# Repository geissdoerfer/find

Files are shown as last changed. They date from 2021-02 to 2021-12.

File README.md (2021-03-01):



# Efficient neighbor discovery and synchronization in battery-free wireless networks with FIND and FLYNC

This repository hosts the artifacts accompanying our NSDI 2021 paper, which introduces FIND and FLYNC.
FIND is the first neighbor discovery protocol for battery-free networks; it uses randomized waiting to minimize discovery latency in the face of intermittency.
FLYNC synchronizes indoor light harvesting devices to the powerline-induced brightness variations of state-of-the-art lamps; it further speeds up discovery when used in tandem with FIND.

In addition to the Python implementation of the analytical FIND model, we provide the hardware design of the prototype battery-free node and the source code of the firmware we used to evaluate FIND and FLYNC.

To get an overview, visit [our website](https://find.nes-lab.org).
For a detailed description and evaluation results, take a look at [our paper](https://nes-lab.org/pubs/2021-Geissdoerfer-Find.pdf).

## FIND Python Model

We provide a Python implementation of the analytical model of the FIND protocol, allowing to reproduce key results of our paper.
For a detailed description and examples, check out the [`/model`](./model/) directory.

## Hardware Design

We built a tiny, battery-free wireless node to evaluate FIND and FLYNC on real hardware.
The [`/hardware`](./hardware) directory contains the corresponding schematics and layout files.

## Firmware

The C code in the [`/firmware`](./firmware) directory implements the FIND protocol and the FLYNC synchronization mechanism on our prototype battery-free node.

## People

FIND and FLYNC are being developed at the Networked Embedded Systems Lab at TU Dresden.

The main contributors are:

 - [Kai Geissdoerfer](https://scholar.google.com/citations?user=k8YZfQEAAAAJ)
 - [Marco Zimmerling](https://wwwpub.zih.tu-dresden.de/~mzimmerl/)

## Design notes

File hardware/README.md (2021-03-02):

# FIND and FLYNC hardware

This directory contains the design files for a 29mm x 29mm battery-free wireless node.
The node is powered by three IXYS KXOB025-5X3F solar panels and buffers energy in a 47uF multi-layer ceramic capacitor.
It implements a circuit to extract a clock signal from variations of the solar panel current caused by powerline flicker of lamps.

Key specifications:
 - TI BQ25505 boost charger with maximum power point tracking
 - Nordic Semiconductor nRF52840 2.4GHz wireless MCU (BLE/802.15.4)
    - ARM Cortex-M4F 64MHz CPU with FPU
    - 1MB flash, 256kB S-RAM
 - 47uF capacitor in 0805 package

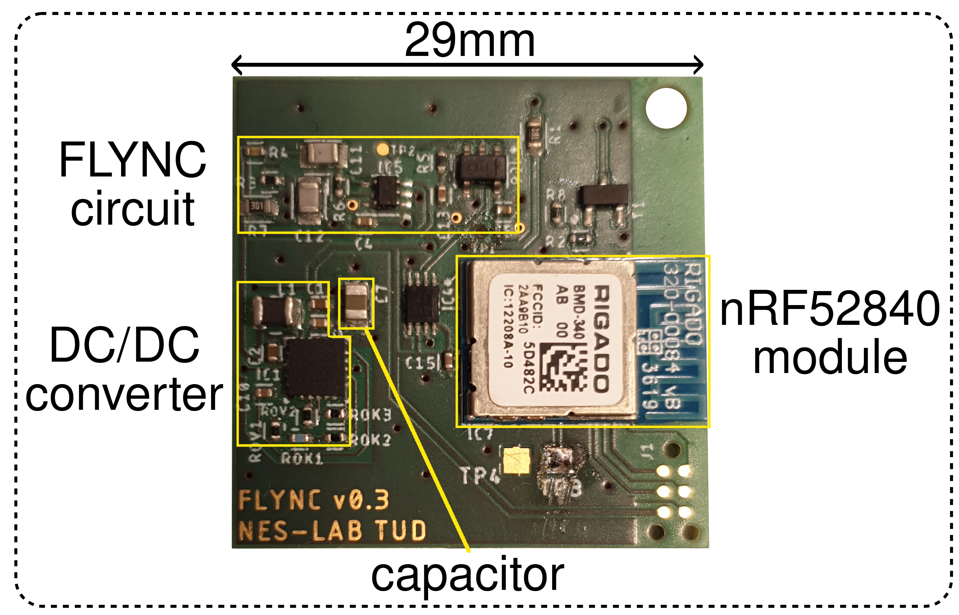
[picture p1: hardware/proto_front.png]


If you have questions or need help with manufacturing the hardware, get in touch with us!

## Pinout

We use a head-less 6-pin Tag-Connect header to break out 6 signals from the FLYNC node.

| Pin number | Signal | Description |
|---|---|---|
| 1 | SWDIO | ARM Serial Wire Debug I/O |
| 2 | SWDCLK | ARM Serial Wire Debug Clock |
| 3 | PIN_DBG1 | nRF52 GPIO for debugging via e.g. UART |
| 4 | PIN_DBG2 | nRF52 GPIO for debugging via e.g. UART |
| 5 | VCC | Output of BQ25504 and supply of nRF52  |
| 6 | GND | Ground |

Use a [Tag-Connect TC2030-IDC-NL cable](https://www.tag-connect.com/product/tc2030-idc-nl) cable to connect to this header:

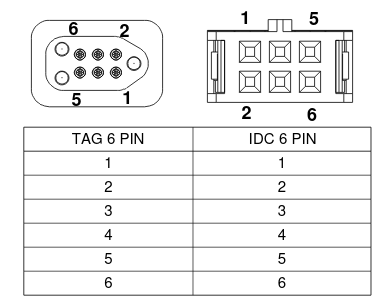
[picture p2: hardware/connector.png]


## Development setup

We found the following setup convenient:

 - Lab bench power supply with 3.3V output
 - Breadboard and some jumper cables
 - [J-Link Mini Edu](https://www.segger.com/products/debug-probes/j-link/models/j-link-edu-mini/)
 - SPST push button
 - [Tag-Connect TC2030-IDC-NL cable](https://www.tag-connect.com/product/tc2030-idc-nl)

Connect the power supply GND to the breadboard GND rail and the power supply 3.3V to the breadboard power rail.
Connect GND (pin 6) of the cable to the GND rail on the breadboard and VCC (pin 5) of the cable to any unused row of the breadboard.
Connect the push button between this rail (with node VCC) and the breadboard 3.3V rail.
Connect the Vref of the J-Link to the 3.3V rail of the breadboard and the GND of the J-Link to the GND rail of the breadboard.
Finally, connect the SWDIO and SWDCLK pins of the J-Link to pins 1 and 2 of the cable.

By pushing the button, you can temporarily power the node from the 3.3V power supply to flash new code.
After releasing the push button, the node will continue to run from harvested energy.

For debugging, you can attach a logic analyzer or scope to pins 3 and 4 of the cable and an analog channel to the node's voltage rail (pin 5).
Keep in mind that there may be significant current flowing into these inputs, interfering with the node's operation.

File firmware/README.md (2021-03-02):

# FIND and FLYNC firmware

The C code in this directory runs the FIND protocol together with the FLYNC synchronization mechanism on the battery-free node hardware provided in `../hardware`.

## Prerequisites

To get started, you need:

 - Two battery-free sensor nodes
 - A [Tag-Connect TC2030-IDC-NL cable](https://www.tag-connect.com/product/tc2030-idc-nl)
 - A programmer compatible with SWD and the nRF52. For example, the [J-Link Mini Edu](https://www.segger.com/products/debug-probes/j-link/models/j-link-edu-mini/), the [Black Magic Probe](https://github.com/blacksphere/blackmagic/wiki) or a [nRF52-DK](https://www.nordicsemi.com/Software-and-Tools/Development-Kits/nRF52-DK)
 - A 3.3V power supply
 - A reasonably bright lamp with sufficient powerline flicker. All incandescent and fluorescent lamps as well as most cheap LED lamps should work

## Getting started

### Building
 - Make sure you have the [GNU Arm Embedded Toolchain](https://developer.arm.com/tools-and-software/open-source-software/developer-tools/gnu-toolchain/gnu-rm/downloads) installed
 - If `arm-none-eabi-gcc` is not in your path, set the environment variable `GNU_INSTALL_ROOT` accordingly, e.g., `export GNU_INSTALL_ROOT=/opt/toolchain/` (note the trailing foreslash)
 - Download the nRF5 SDK from [here.](https://www.nordicsemi.com/Software-and-tools/Software/nRF5-SDK/Download "here") (you don't need a SoftDevice) and extract it
 - Set the environment variables `SDK_ROOT` to the corresponding absolute path, e.g., `export SDK_ROOT=/home/user/nRF5_SDK_17.0.2_d674dde/`
 - run `make`

### Flashing
 - Download and install the [nRF-Command-Line-Tools](https://www.nordicsemi.com/Software-and-tools/Development-Tools/nRF-Command-Line-Tools/Download) following the official instructions.
 - Connect your programmer to your PC
 - Connect your programmer to one of the FLYNC sensor nodes according to the corresponding [README](../hardware/README.md)
 - run `make flash`

### Testing

After flashing the two nodes, you can place them next to each other under the lamp.
You should see their LEDs flashing simultaneously every now and then, indicating a successful rendezvous.
Cover the solar panels with your hands to reset the nodes.
Because of the small energy storage, they lose track of time and state after a few seconds.
After removing your hands, you should soon see the nodes blinking simultaneously again, indicating another successful rendezvous.
Take one node to another lamp of the same type close by, i.e., within radio range.
You should still see each of the nodes blinking occasionally.

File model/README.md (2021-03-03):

# FIND model

This directory contains a Python implementation of the analytical FIND model presented in Section 2 of our NSDI 2021 paper.
As illustrated below, the model allows to compute the network discovery latency as a function of several key parameters (e.g., delay distribution, charging times of the nodes).
It is also possible to obtain more detailed insights by computing the probability for a node to become active in a slot and the probability for a link to be discovered in a slot.

## Installation

Install the python package together with the requirements for the examples using either

```
pip install neslab.find[examples]
```

or

```
pipenv install neslab.find[examples]
```

## Usage

Instantiate the model with a uniform distribution with scale parameter 10 and three nodes with charging times of 100, 125 and 200 slots that become active for the first time without an offset:

```python
import matplotlib.pyplot as plt
from neslab.find import Model

m = Model(10, "Uniform", [100, 125, 200], offset=0)
```

Compute for every node the probability of being active in a slot and plot the results:

```python
act = m.activity()
plt.plot(act[:2000])
plt.show()
```

Compute the cumulative distribution function (cdf) of the slot in which each of the three links between the three nodes is discovered and plot the results:

```python
cdfs = m.cdf()
plt.plot(cdfs)
plt.show()
```

Compute the fraction of discovered links and plot the result:

```python
dff = m.disco_frac()
plt.plot(dff)
plt.show()
```

Compute the discovery latency:

```python
lat = m.disco_latency()
print(f"Discovery latency: {lat} slots")
```

## Examples

We provide more involved example scripts in the [examples](./examples) directory:

To compare the probability of activity and the cdf of the corresponding discovery latency of two nodes with a charging time of 30 and 60 slots, using a uniform delay distribution, call

```
python examples/plot_example.py
```

To compare the discovery latency of two nodes when using different distributions across a range of their scale parameters, run

```
python examples/compare_dists.py
```

To plot the discovery latency of a clique of nodes over the node density, run

```
python examples/plot_density.py
```

To optimize the scale parameter of the geometric distribution to a range of charging times, run

```
python examples/optimize_scale.py
```

## Reproduce key results

We used the code provided in this directory to gain the insights presented in Section 2 of [our NSDI 2021 paper](https://nes-lab.org/pubs/2021-Geissdoerfer-Find.pdf).
We invite you to reproduce our results with the scripts provided in the [reproducibility](./reproducibility) directory.
Figures 3 and 4 can be reproduced with the script `examples/plot_example.py`.
The calculations for Figures 5 and 6, and for the lookup table for the online implementation take significant computing resources and require a high performance computing system with a large number of CPUs to complete in a reasonable amount of time.
We use [ray](https://ray.io/) to run the calculations on a distributed memory computing cluster.

### Setup your cluster

Install `ray` and `neslab.find` on all nodes in your cluster. The exact installation procedure depends on the specific cluster setup and your access rights. If in doubt, contact the cluster provider.

First, setup the `head` node responsible for managing the workload across the cluster by starting the head process with:

```
ray start --block --head --redis-password=yourpassword
```

Next, start a worker process on each other node in your cluster, providing the IP address of your head node as  `address`:

```
ray start --block --address=[IP of head node] --redis-password=yourpassword
```

### Comparing distributions

To reproduce the results shown in Figure 5 in our paper, you can compute the neighbor discovery performance of different distributions for a higher number of sampling points than with the example from `examples/compare_dists` according to the following instructions.

Login to any of the nodes in the cluster, clone the repository and run

```
python reproducibility/compute_dists.py -a [IP of head node] -p yourpassword -o results_dists.csv
```

Copy the `results_dists.csv` to your local machine and generate the plot with

```
python reproducibility/plot_dists.py -i results_dists.csv
```

### Fit the scale parameter for various scenarios

As a basis for reproducing the results shown in Figure 6 in our paper, and to generate the lookup table for the online implementation, first fit the scale parameter of the geometric distribution for different combinations of charging time and number of nodes with

```
python reproducibility/fit_scale.py -a [IP of head node] -p yourpassword -o results_scale.csv
```

This will store the results in a csv file under `results_scale.csv`.

### Discovery latency versus network density

To reproduce Figure 6 in our paper, use the results from the previous step to compute ND performance for different strategies and increasing network densities by running (on the cluster)

```
python reproducibility/compute_density.py -a [IP of head node] -p yourpassword -i results_scale.csv -o results_density.csv
```

Copy the `results_density.csv` to your local machine and generate the plot with

```
python reproducibility/plot_density.py -i results_density.csv
```

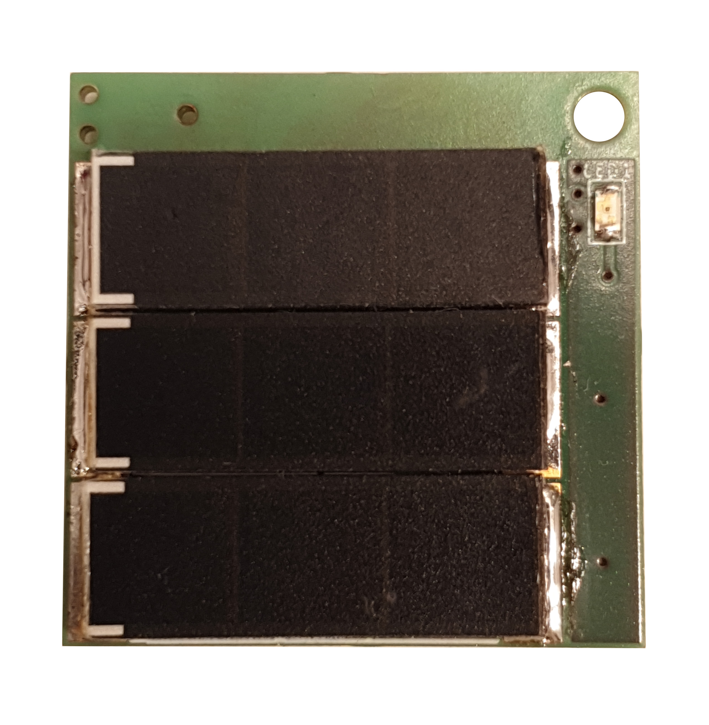
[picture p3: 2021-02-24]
hardware/proto_back.jpg

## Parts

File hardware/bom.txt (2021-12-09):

You find the BOM under https://octopart.com/bom-tool/tjKuMvbW

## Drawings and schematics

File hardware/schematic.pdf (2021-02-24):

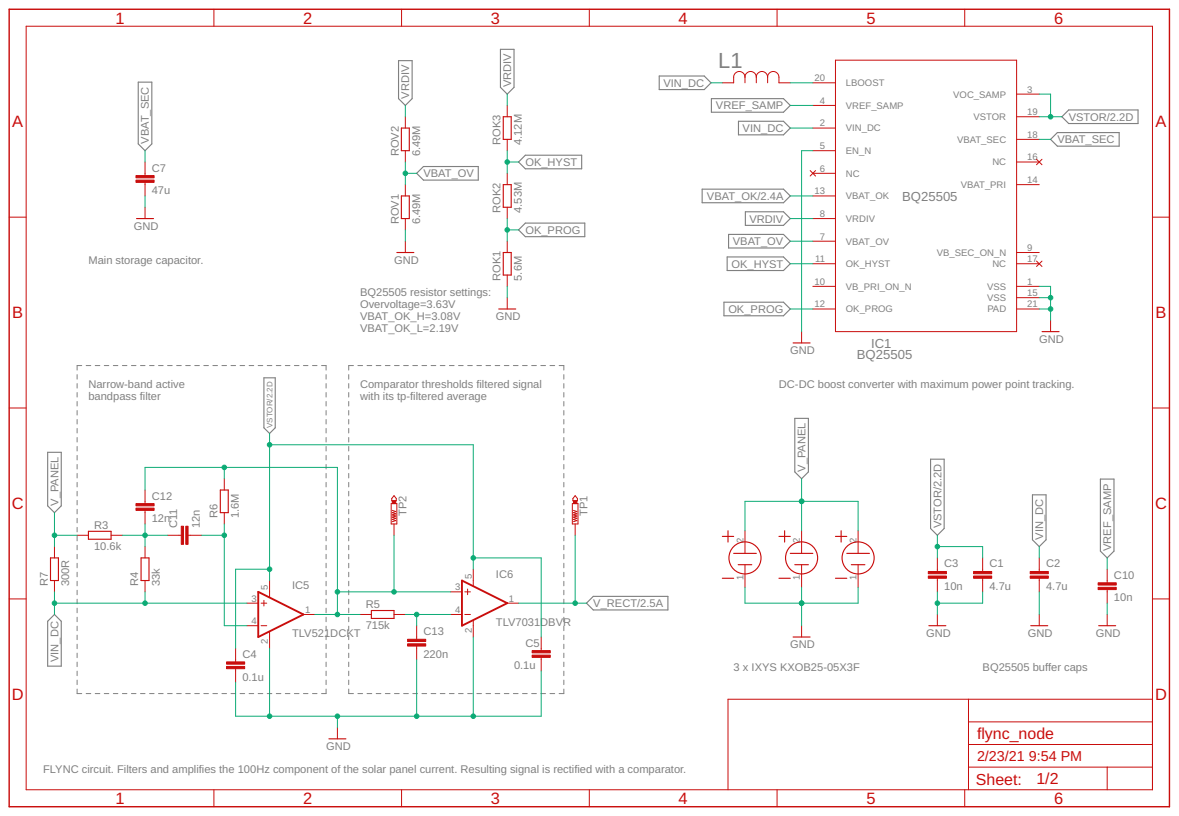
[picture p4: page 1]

FLYNC circuit. Filters and amplifies the 100Hz component of the solar panel current. Resulting signal is rectified with a comparator.

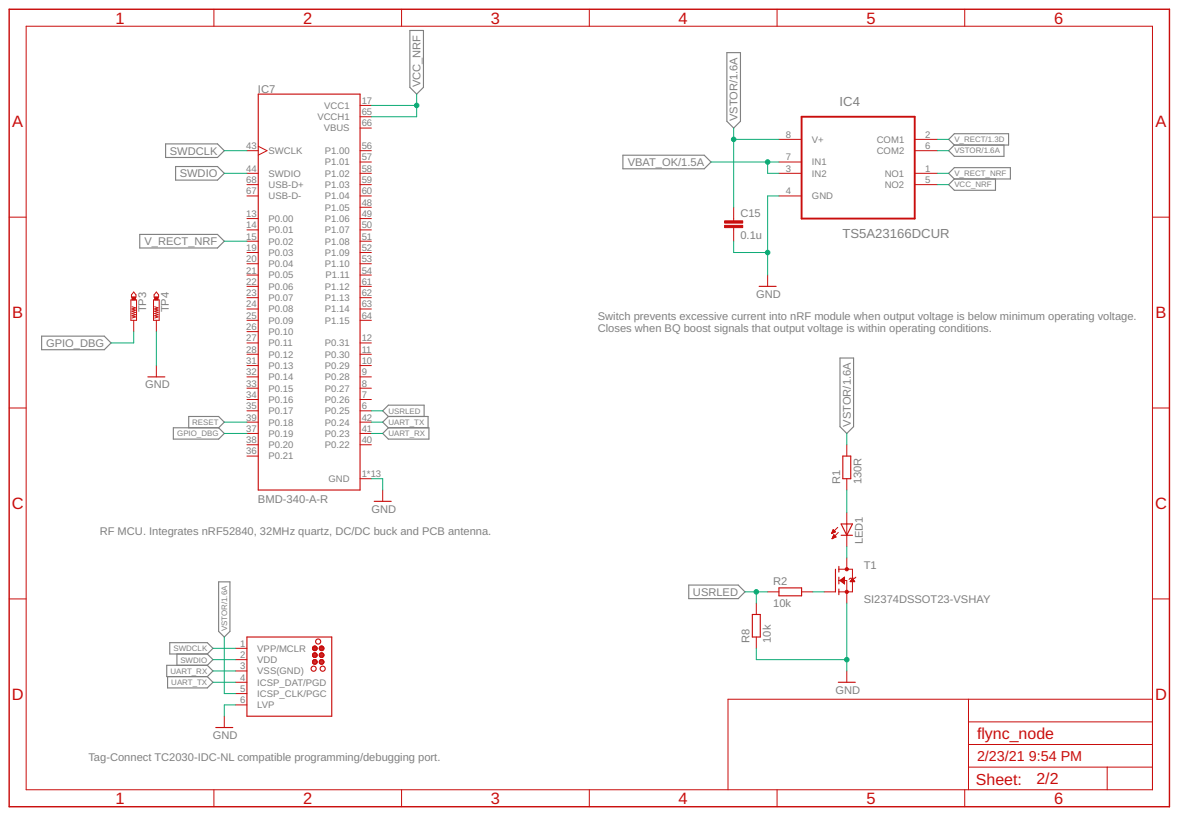
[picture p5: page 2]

Switch prevents excessive current into nRF module when output voltage is below minimum operating voltage. Closes when BQ boost signals that output voltage is within operating conditions.

RF MCU. Integrates nRF52840, 32MHz quartz, DC/DC buck and PCB antenna.

Tag-Connect TC2030-IDC-NL compatible programming/debugging port.

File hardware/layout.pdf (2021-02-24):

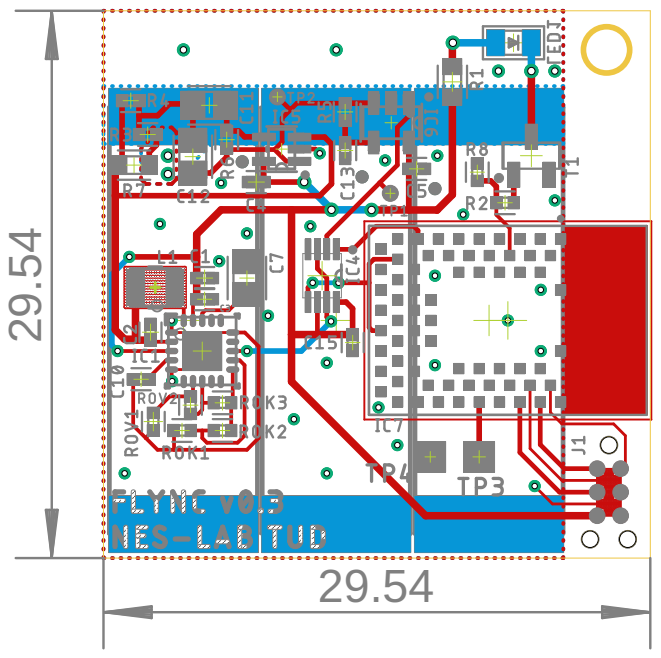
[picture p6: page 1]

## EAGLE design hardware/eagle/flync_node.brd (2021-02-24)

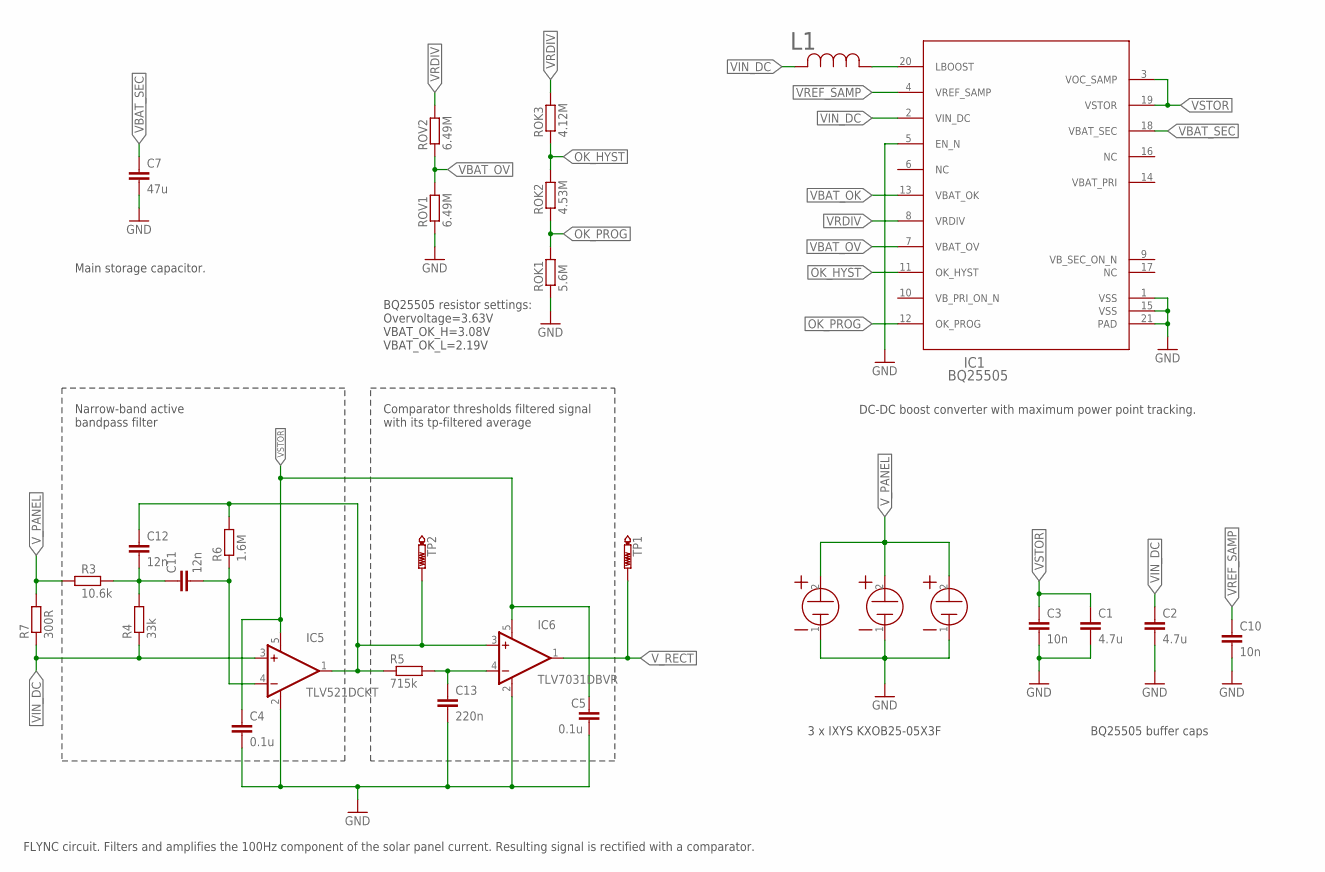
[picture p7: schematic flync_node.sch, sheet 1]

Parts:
C1, C2: 4.7u; CAPC1005X55
C3, C10: 10n; CAPC1005X55
C4, C5: 0.1u; CAPC1005X55
C7: 47u; CAPC2012X145
C11, C12: 12n; CAPC2012X145
C13: 220n; CAPC1005X55
H1, H2, H3: IXYSKXOB25-05X3F; IXYS23X8
IC1: BQ25505; RGR0020A
IC5: TLV521DCKT; DCK5
IC6: TLV7031DBVR; DBV5-L
L1: LBR2518T220KIND1007_47N_TAI-L; IND1007_47N_TAI-L
R3: 10.6k; RESC1005X40
R4: 33k; RESC1005X40
R5: 715k; RESC1005X40
R6: 1.6M; RESC1005X40
R7: 300R; RESC1608X55
ROK1: 5.6M; RESC1005X40
ROK2: 4.53M; RESC1005X40
ROK3: 4.12M; RESC1005X40
ROV1, ROV2: 6.49M; RESC1005X40
TP1, TP2: PTR1TP08R; TP08R

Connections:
GND: C1.2, C2.2, C3.2, C4.2, C5.2, C7.2, C10.2, C13.2, H1.1, H2.1, H3.1, IC1.1 (VSS), IC1.5 (EN_N), IC1.15 (VSS), IC1.21 (PAD), IC5.2 (V-), IC6.2 (V-), ROK1.1, ROV1.1; also elsewhere on the board
unnamed: IC1.20 (LBOOST), L1.1
unnamed: C11.1, C12.2, R3.2, R4.2
unnamed: C11.2, IC5.4 (-IN), R6.1
unnamed: C12.1, IC5.1 (OUT), IC6.3 (+IN), R5.1, R6.2, TP2.TP
unnamed: C13.1, IC6.4 (-IN), R5.2
OK_HYST: IC1.11 (OK_HYST), ROK2.2, ROK3.1
OK_PROG: IC1.12 (OK_PROG), ROK1.2, ROK2.1
VBAT_OK: IC1.13 (VBAT_OK); also elsewhere on the board
VBAT_OV: IC1.7 (VBAT_OV), ROV1.2, ROV2.1
VBAT_PRI: IC1.14 (VBAT_PRI)
VBAT_SEC: C7.1, IC1.18 (VBAT_SEC)
VB_SEC_ON_N: IC1.9 (VB_SEC_ON_N)
VIN_DC: C2.1, IC1.2 (VIN_DC), IC5.3 (+IN), L1.2, R4.1, R7.1
VRDIV: IC1.8 (VRDIV), ROK3.2, ROV2.2
VREF_SAMP: C10.1, IC1.4 (VREF_SAMP)
VSTOR: C1.1, C3.1, C4.1, C5.1, IC1.3 (VOC_SAMP), IC1.19 (VSTOR), IC5.5 (V+), IC6.5 (V+); also elsewhere on the board
V_PANEL: H1.2, H2.2, H3.2, R3.1, R7.2
V_RECT: IC6.1 (OUT), TP1.TP; also elsewhere on the board

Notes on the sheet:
FLYNC circuit. Filters and amplifies the 100Hz component of the solar panel current. Resulting signal is rectified with a comparator.
Narrow-band active bandpass filter
Comparator thresholds filtered signal with its tp-filtered average
DC-DC boost converter with maximum power point tracking.
BQ25505 resistor settings: Overvoltage=3.63V VBAT_OK_H=3.08V VBAT_OK_L=2.19V
Main storage capacitor.
BQ25505 buffer caps
3 x IXYS KXOB25-05X3F

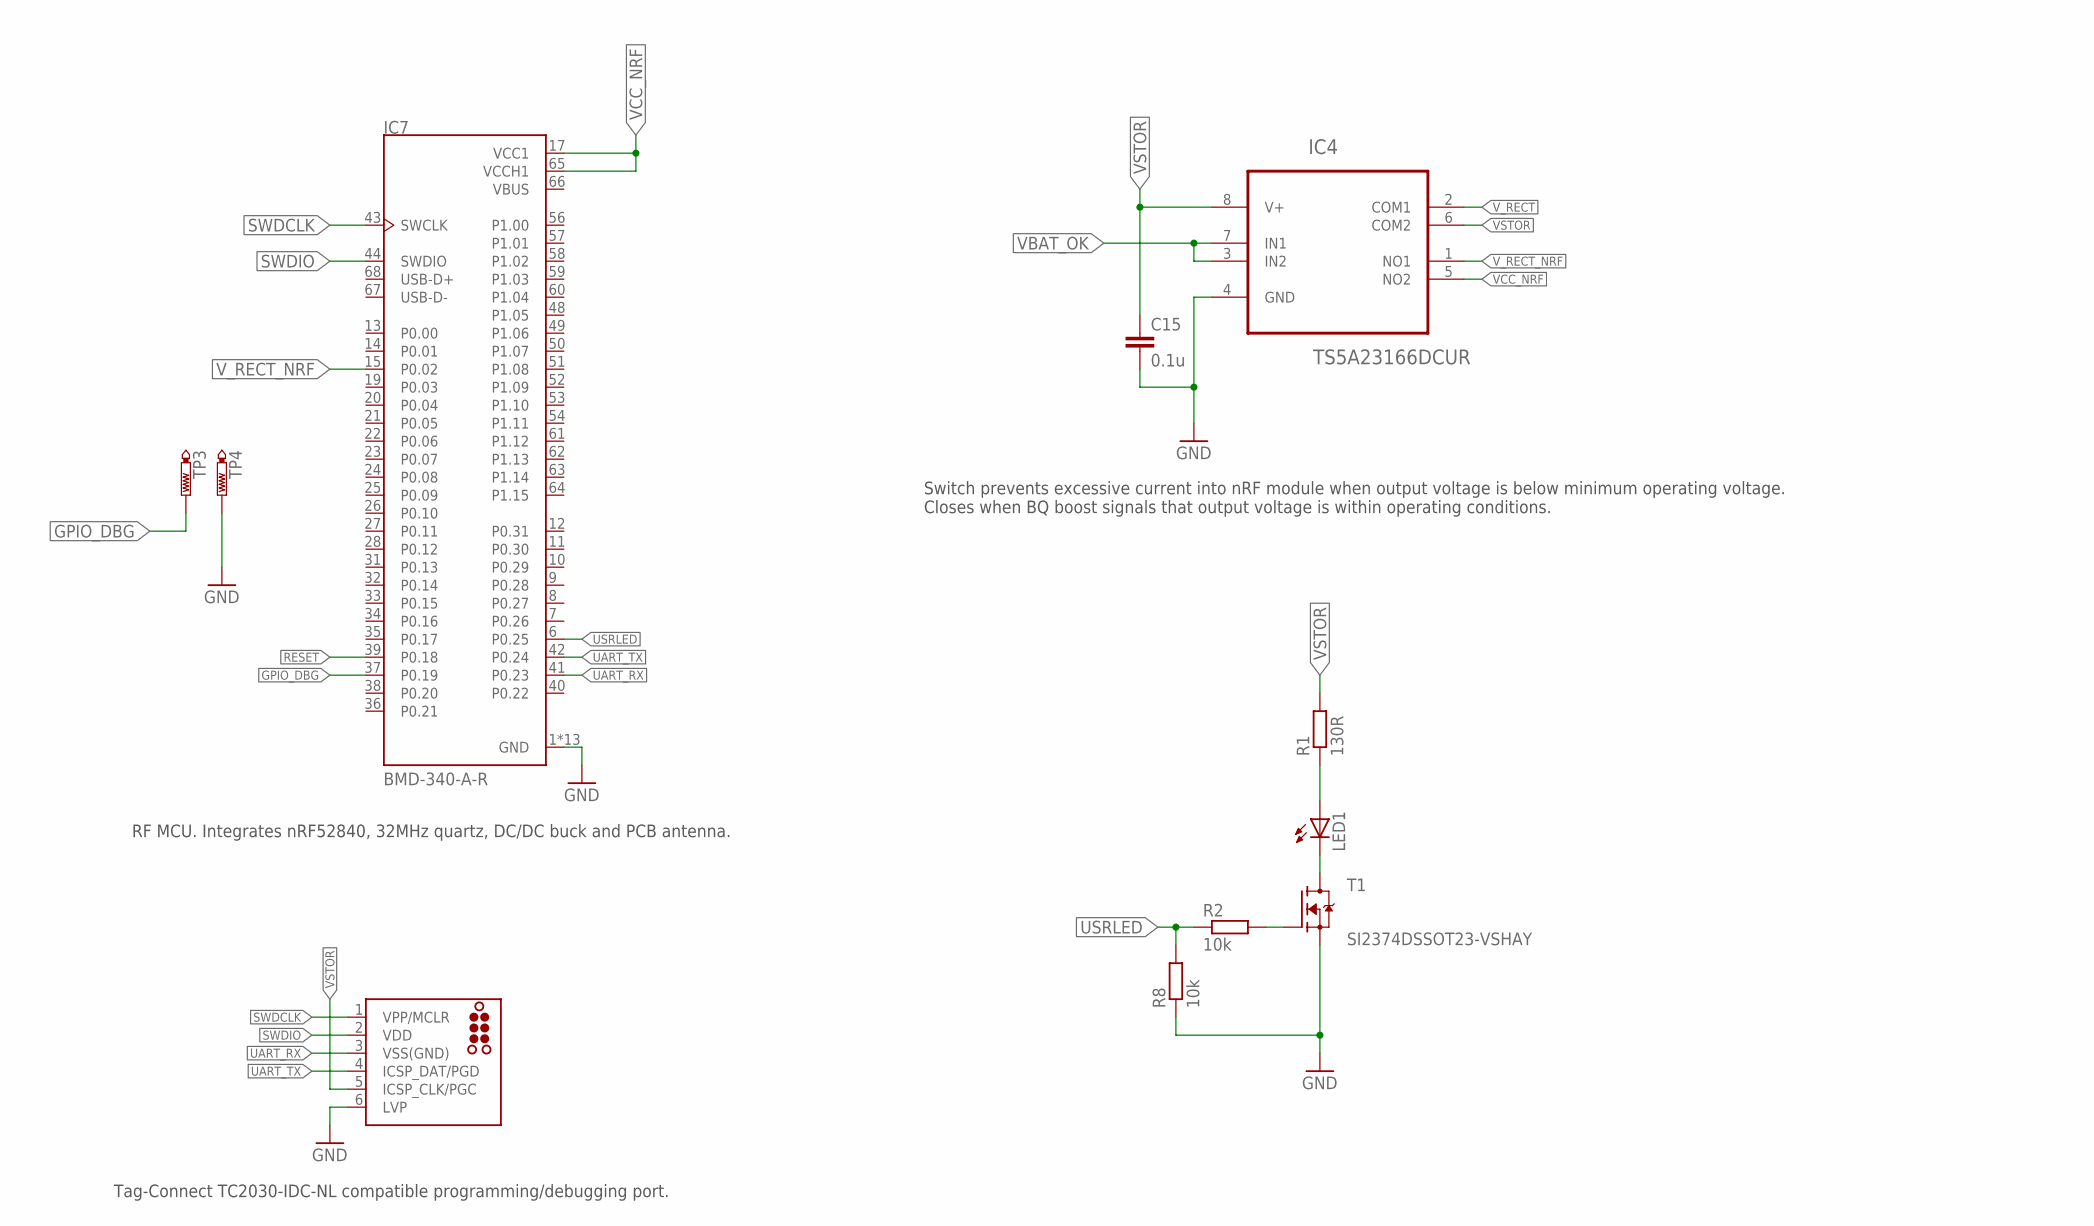
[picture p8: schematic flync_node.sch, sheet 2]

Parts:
C15: 0.1u; CAPC1005X55
IC4: TS5A23166DCUR; SOP50P310X90-8N
IC7: BMD-340-A-R; RIGADO_BMD-340-A-R
J1: TC2030-MCP-NL
LED1: 598-8130-107FLED_0805; LEDC2012X75
R1: 130R; RESC1608X55
R2, R8: 10k; RESC1005X40
T1: SI2374DSSOT23-VSHAY; SOT95P237X112-3
TP3, TP4: PTR1TP16SQ; TP16SQ

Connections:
GND: C15.2, IC4.4 (GND), IC7.1 (GND), IC7.2 (GND), IC7.3 (GND), IC7.4 (GND), IC7.5 (GND), IC7.16 (GND), IC7.18 (GND), IC7.29 (GND), IC7.30 (GND), IC7.45 (GND), IC7.46 (GND), IC7.47 (GND), IC7.55 (GND), J1.6 (LVP), R8.1, T1.2 (S), TP4.TP; also elsewhere on the board
GPIO_DBG: IC7.37 (P0.19), TP3.TP
unnamed: LED1.2 (A), R1.1
unnamed: LED1.1 (C), T1.3 (D)
unnamed: R2.2, T1.1 (G)
RESET: IC7.39 (P0.18)
SWDCLK: IC7.43 (SWCLK), J1.1 (VPP/MCLR)
SWDIO: IC7.44 (SWDIO), J1.2 (VDD)
UART_RX: IC7.41 (P0.23), J1.3 (VSS(GND))
UART_TX: IC7.42 (P0.24), J1.4 (ICSP_DAT/PGD)
USRLED: IC7.6 (P0.25), R2.1, R8.2
VBAT_OK: IC4.3 (IN2), IC4.7 (IN1); also elsewhere on the board
VBUS: IC7.66 (VBUS)
VCC_NRF: IC4.5 (NO2), IC7.17 (VCC1), IC7.65 (VCCH1)
VSTOR: C15.1, IC4.6 (COM2), IC4.8 (V+), J1.5 (ICSP_CLK/PGC), R1.2; also elsewhere on the board
V_RECT: IC4.2 (COM1); also elsewhere on the board
V_RECT_NRF: IC4.1 (NO1), IC7.15 (P0.02)

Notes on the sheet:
Switch prevents excessive current into nRF module when output voltage is below minimum operating voltage. Closes when BQ boost signals that output voltage is within operating conditions.
RF MCU. Integrates nRF52840, 32MHz quartz, DC/DC buck and PCB antenna.
Tag-Connect TC2030-IDC-NL compatible programming/debugging port.

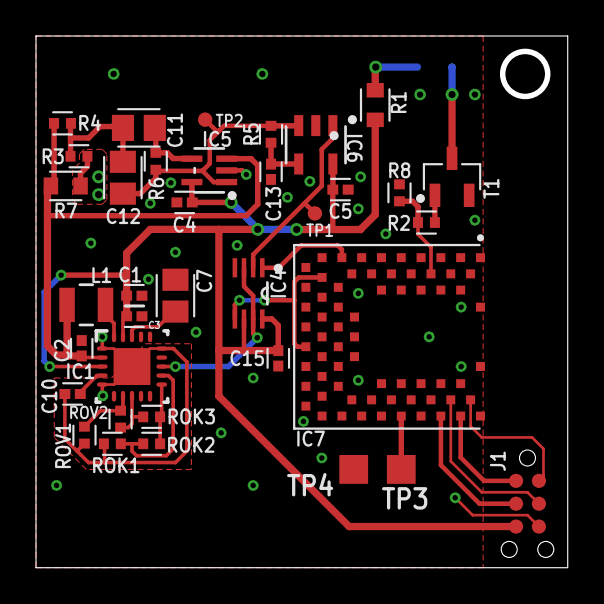
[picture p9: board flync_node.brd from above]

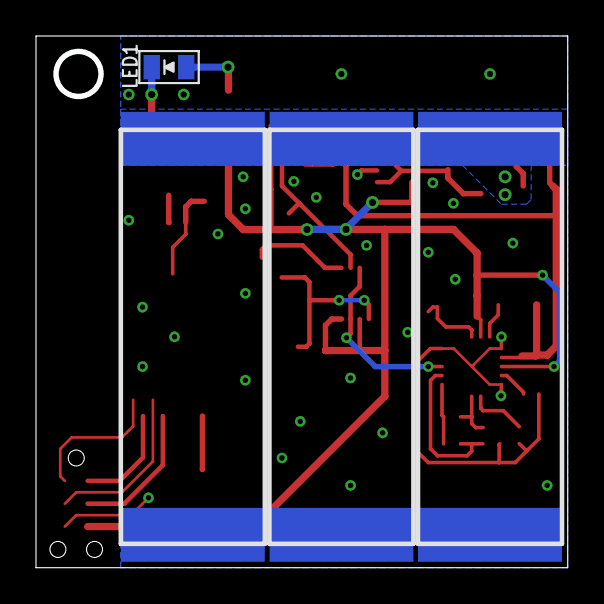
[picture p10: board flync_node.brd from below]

Board: 2 copper layers, 29.5 x 29.5 mm, 40 parts (4 on the bottom side), 28 nets.

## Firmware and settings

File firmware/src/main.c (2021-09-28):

#include <stdbool.h>
#include <stdint.h>
#include <string.h>

#include "nrf.h"
#include "nrf52840.h"
#include "nrf52840_bitfields.h"
#include "nrf_clock.h"
#include "nrf_delay.h"
#include "nrf_gpio.h"
#include "nrf_gpiote.h"
#include "nrf_power.h"
#include "nrf_radio.h"
#include "nrf_saadc.h"
#include "nrf_uart.h"

#include "flync.h"
#include "printf.h"

/* Minimum voltage for becoming active */
#define V_THR_ON 3.3
/* Power off threshold */
#define V_THR_OFF NRF_POWER_POFTHR_V27

/* Maximum voltage before converter goes into overvoltage protection mode */
#define V_THR_MAX 3.5

/**
 * Protocol protothread
 *
 * Implements the key protocol handling the three phases, i.e. charging,
 * waiting and discovery. Yields while charging and waiting, but blocks during
 * actual discovery period.
 *
 * @param pt Handle of protothread
 *
 */
__attribute__((long_call, section(".ramfunctions"))) void
protocol(struct pt *pt) {
  pt_begin(pt);

  static struct pt pt_disco_h;
  static volatile pt_event_t *clk_evt;
  static volatile pt_event_t *pof_evt;

  static disco_data_t *disco_data;

  static unsigned int t_start;
  static unsigned int t_charge;

  for (;;) {
    /* Timestamp beginning of charging period */
    t_start = timer_now();

    /* Make sure next reading from ADC is recent */
    pt_yield(pt);

    /* Wait until voltage reaches turn-on threshold */
    pt_wait(pt, adc_read_vcap() > V2ADC(V_THR_ON));
    t_charge = timer_now() - t_start;

    /* Maximum waiting time equals charging time*/
    unsigned int wait_time = geometric_itf_sample(lookup_scale(t_charge));

    /* Wait for waiting time or until capacitor is fully charged */
    clk_evt = timer_flync_wait(wait_time);
    pt_wait(pt, pt_event_get(clk_evt) || (adc_read_vcap() > V2ADC(V_THR_MAX)));

#if FLYNC_ACTIVE
    pt_disco(pt, &pt_disco_h, (uint16_t)t_charge, 26, flync_phase2rtctcks(1));
#else
    pt_disco(pt, &pt_disco_h, (uint16_t)t_charge, 26, 0);
#endif
    pof_evt = pofwarn_request_evt(V_THR_OFF);

    while ((disco_data = disco_results_pop()) != NULL) {
      /* Switch on LED */
      NRF_P0->OUTSET = (1 << FLYNC_LED);
    }

    while (!pt_event_get(pof_evt)) {
      __NOP();
    }
    /* Switch off LED */
    NRF_P0->OUTCLR = (1 << FLYNC_LED);

    wdt_reload();
  }
  pt_end(pt);
}

/**
 * Protothread loop
 *
 * Iterates all threads and enters low power mode when all blocking.
 *
 */
__attribute__((long_call, section(".ramfunctions"))) void thread_loop(void) {
  struct pt pt_protocol = pt_init();
  while (1) {
    protocol(&pt_protocol);
    enter_low_power();
  };
}

int main(void) {

  enable_fpu();

  nrf_gpio_cfg_output(FLYNC_LED);

  nrf_gpio_pin_clear(FLYNC_LED);

  // uart_init(FLYNC_PIN_DBG1);

  /* DC/DC reduces power consumption at high current draw */
  nrf_power_dcdcen_set(true);
  adc_init();
  prng_seed();

  /* Use device address as beacon/ack payload */
  disco_init(RADIO_NO_GPIO);
  flync_init(FLYNC_PIN_DBG2);

  /* 5 seconds watch dog */
  wdt_init(5);

  /* From now on, we will run in RAM */
  volatile uint32_t ramfunc = (uint32_t)thread_loop;
  asm("ldr pc, [%[addr], #0]\t\n" : : [addr] "r"(&ramfunc));
}

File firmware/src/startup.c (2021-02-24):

#include "nrf52840.h"
#include "nrf52840_bitfields.h"

#define STACK_TOP (void *)0x20002000

extern unsigned long _stext;
extern unsigned long _sbss;
extern unsigned long _sdata;
extern unsigned long _etext;
extern unsigned long _ebss;
extern unsigned long _edata;
extern unsigned long _isr_vector_start;
extern unsigned long _isr_vector_end;

volatile unsigned long ram_vector_table[64] __attribute__((aligned(128)));

/* Exceptions */
void NMI_Handler(void) __attribute__((weak, alias("Default_Handler")));
void HardFault_Handler(void) __attribute__((weak, alias("Default_Handler")));
void MemManage_Handler(void) __attribute__((weak, alias("Default_Handler")));
void BusFault_Handler(void) __attribute__((weak, alias("Default_Handler")));
void UsageFault_Handler(void) __attribute__((weak, alias("Default_Handler")));
void SVC_Handler(void) __attribute__((weak, alias("Default_Handler")));
void DebugMon_Handler(void) __attribute__((weak, alias("Default_Handler")));
void PendSV_Handler(void) __attribute__((weak, alias("Default_Handler")));
void SysTick_Handler(void) __attribute__((weak, alias("Default_Handler")));

void POWER_CLOCK_IRQHandler(void)
    __attribute__((weak, alias("Default_Handler")));
void RADIO_IRQHandler(void) __attribute__((weak, alias("Default_Handler")));
void UARTE0_UART0_IRQHandler(void)
    __attribute__((weak, alias("Default_Handler")));
void SPIM0_SPIS0_TWIM0_TWIS0_SPI0_TWI0_IRQHandler(void)
    __attribute__((weak, alias("Default_Handler")));
void SPIM1_SPIS1_TWIM1_TWIS1_SPI1_TWI1_IRQHandler(void)
    __attribute__((weak, alias("Default_Handler")));
void NFCT_IRQHandler(void) __attribute__((weak, alias("Default_Handler")));
void GPIOTE_IRQHandler(void) __attribute__((weak, alias("Default_Handler")));
void SAADC_IRQHandler(void) __attribute__((weak, alias("Default_Handler")));
void TIMER0_IRQHandler(void) __attribute__((weak, alias("Default_Handler")));
void TIMER1_IRQHandler(void) __attribute__((weak, alias("Default_Handler")));
void TIMER2_IRQHandler(void) __attribute__((weak, alias("Default_Handler")));
void RTC0_IRQHandler(void) __attribute__((weak, alias("Default_Handler")));
void TEMP_IRQHandler(void) __attribute__((weak, alias("Default_Handler")));
void RNG_IRQHandler(void) __attribute__((weak, alias("Default_Handler")));
void ECB_IRQHandler(void) __attribute__((weak, alias("Default_Handler")));
void CCM_AAR_IRQHandler(void) __attribute__((weak, alias("Default_Handler")));
void WDT_IRQHandler(void) __attribute__((weak, alias("Default_Handler")));
void RTC1_IRQHandler(void) __attribute__((weak, alias("Default_Handler")));
void QDEC_IRQHandler(void) __attribute__((weak, alias("Default_Handler")));
void COMP_LPCOMP_IRQHandler(void)
    __attribute__((weak, alias("Default_Handler")));
void SWI0_EGU0_IRQHandler(void) __attribute__((weak, alias("Default_Handler")));
void SWI1_EGU1_IRQHandler(void) __attribute__((weak, alias("Default_Handler")));
void SWI2_EGU2_IRQHandler(void) __attribute__((weak, alias("Default_Handler")));
void SWI3_EGU3_IRQHandler(void) __attribute__((weak, alias("Default_Handler")));
void SWI4_EGU4_IRQHandler(void) __attribute__((weak, alias("Default_Handler")));
void SWI5_EGU5_IRQHandler(void) __attribute__((weak, alias("Default_Handler")));
void TIMER3_IRQHandler(void) __attribute__((weak, alias("Default_Handler")));
void TIMER4_IRQHandler(void) __attribute__((weak, alias("Default_Handler")));
void PWM0_IRQHandler(void) __attribute__((weak, alias("Default_Handler")));
void PDM_IRQHandler(void) __attribute__((weak, alias("Default_Handler")));
void MWU_IRQHandler(void) __attribute__((weak, alias("Default_Handler")));
void PWM1_IRQHandler(void) __attribute__((weak, alias("Default_Handler")));
void PWM2_IRQHandler(void) __attribute__((weak, alias("Default_Handler")));
void SPIM2_SPIS2_SPI2_IRQHandler(void)
    __attribute__((weak, alias("Default_Handler")));
void RTC2_IRQHandler(void) __attribute__((weak, alias("Default_Handler")));
void I2S_IRQHandler(void) __attribute__((weak, alias("Default_Handler")));
void FPU_IRQHandler(void) __attribute__((weak, alias("Default_Handler")));
void USBD_IRQHandler(void) __attribute__((weak, alias("Default_Handler")));
void UARTE1_IRQHandler(void) __attribute__((weak, alias("Default_Handler")));
void QSPI_IRQHandler(void) __attribute__((weak, alias("Default_Handler")));
void CRYPTOCELL_IRQHandler(void)
    __attribute__((weak, alias("Default_Handler")));
void PWM3_IRQHandler(void) __attribute__((weak, alias("Default_Handler")));
void SPIM3_IRQHandler(void) __attribute__((weak, alias("Default_Handler")));

void c_startup(void);
void dummy_fn(void);

int main();

__attribute__((section(".isr_vector"))) void (*vectors[])(void) = {
    STACK_TOP,
    c_startup,
    NMI_Handler,
    HardFault_Handler,
    MemManage_Handler,
    BusFault_Handler,
    UsageFault_Handler,
    0UL,
    0UL,
    0UL,
    0UL,
    SVC_Handler,
    DebugMon_Handler,
    0UL,
    PendSV_Handler,
    SysTick_Handler,
    POWER_CLOCK_IRQHandler,
    RADIO_IRQHandler,
    UARTE0_UART0_IRQHandler,
    SPIM0_SPIS0_TWIM0_TWIS0_SPI0_TWI0_IRQHandler,
    SPIM1_SPIS1_TWIM1_TWIS1_SPI1_TWI1_IRQHandler,
    NFCT_IRQHandler,
    GPIOTE_IRQHandler,
    SAADC_IRQHandler,
    TIMER0_IRQHandler,
    TIMER1_IRQHandler,
    TIMER2_IRQHandler,
    RTC0_IRQHandler,
    TEMP_IRQHandler,
    RNG_IRQHandler,
    ECB_IRQHandler,
    CCM_AAR_IRQHandler,
    WDT_IRQHandler,
    RTC1_IRQHandler,
    QDEC_IRQHandler,
    COMP_LPCOMP_IRQHandler,
    SWI0_EGU0_IRQHandler,
    SWI1_EGU1_IRQHandler,
    SWI2_EGU2_IRQHandler,
    SWI3_EGU3_IRQHandler,
    SWI4_EGU4_IRQHandler,
    SWI5_EGU5_IRQHandler,
    MWU_IRQHandler,
    TIMER3_IRQHandler,
    TIMER4_IRQHandler,
    PWM0_IRQHandler,
    PDM_IRQHandler,
    0,
    0,
    PWM1_IRQHandler,
    PWM2_IRQHandler,
    SPIM2_SPIS2_SPI2_IRQHandler,
    RTC2_IRQHandler,
    I2S_IRQHandler,
    FPU_IRQHandler,
    USBD_IRQHandler,
    UARTE1_IRQHandler,
    QSPI_IRQHandler,
    CRYPTOCELL_IRQHandler,
    0,
    0,
    PWM3_IRQHandler,
    0,
    SPIM3_IRQHandler,

};

void Default_Handler(void) {

  NRF_P0->PIN_CNF[25] = 0x03;
  while (1) {
    NRF_P0->OUTSET = (1 << 25);
    for (unsigned int i = 0; i < 100000; i++) {
      __NOP();
    }
    NRF_P0->OUTCLR = (1 << 25);
    for (unsigned int i = 0; i < 100000; i++) {
      __NOP();
    }
  };
}
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

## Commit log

2021-02-18 added hardware design files
    [flync_node.brd, flync_node.sch]
2021-02-24 hardware: added schematic and layout as pdf
    [flync_node.brd, flync_node.sch]
2021-02-24 added fimware
    [opt_scale.csv]
2021-12-09 hardware: added link to BOM

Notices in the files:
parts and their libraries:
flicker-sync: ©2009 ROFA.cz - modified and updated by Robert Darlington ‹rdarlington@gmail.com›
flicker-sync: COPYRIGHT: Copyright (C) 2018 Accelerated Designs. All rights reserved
